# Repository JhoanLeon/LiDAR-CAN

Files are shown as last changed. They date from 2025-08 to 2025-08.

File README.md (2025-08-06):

# LiDAR-CAN BRDIGE MODULE - CASE STUDY Robot.com

This project was developed for a Robot.com case study. The entire project was developed using Git/GitHub version control so you can view all commits and incremental progress throughout the project's execution.

The requested deliverables for this case study are located in the OUTPUT folder.

For any questions, suggestions, or recommendations, please contact me by email: je.leon.e@outlook.com

Note: This project is available as a public GitHub repository at the following link: https://github.com/JhoanLeon/LiDAR-CAN

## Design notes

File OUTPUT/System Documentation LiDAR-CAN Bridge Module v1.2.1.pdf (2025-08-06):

## System Documentation

## LiDAR-CAN Bridge Module v1.2.1

### General Description:

The system will handle data flow from MID-360 LiDAR sensor Ethernet interface to CAN-FD bus by using the STM32F401RBT6 MCU as the central processor and data bridge. This MCU will manage the communication between the W5500 Ethernet controller and the TCAN4550RGY CAN-FD controller through independent high-speed SPI buses. Data from the LiDAR will be received via Ethernet, processed by the MCU, and then re-packaged and transmitted onto the CAN-FD bus. Additionally, the board have internal power management circuits to regulate input power to suitable +12VDC and +3.3VDC levels to use in the system components.

### 1. Data Flow Description:

The data flow in the board can be described in four main stages:

1.1. Ethernet Data Reception (LiDAR to W5500):
The Livox MID-360 LiDAR sends point cloud and other data over the Ethernet connection. This data, which is typically encapsulated in UDP packets, is received by the W5500 Ethernet Controller. The W5500's primary role is to handle the low-level physical and data link layers of the Ethernet protocol. It’s hardwired TCP/IP stack automatically manages the network protocol headers and places the payload data into its internal TX/RX buffers.
1.2. Data Transfer (W5500 to STM32F401):
The W5500 notifies the STM32F401RBT6 MCU that new data has arrived in its RX buffer by asserting the interrupt line. The MCU then uses the high-speed SPI bus to read the data from the W5500's buffers. The STM32's firmware is responsible for a few key tasks here:
- Reading the UDP payload from the W5500's buffers.
- Parsing the received data to extract relevant information, such as the point cloud data, time stamps, or status messages.
- Implementing any protocol translation or data filtering logic.
1.3. Data Processing and Translation (STM32F401 MCU):
The STM32F401 MCU will process the raw data from the LiDAR and re-format it into CAN-FD frames. This involves:
- Packet Parsing: Extracting specific data fields from the Ethernet packets. The raw LiDAR point cloud data is often too large to fit into a single CAN-FD frame.
- Data Aggregation or Fragmentation: Depending on the data being sent, the MCU may need to aggregate smaller data points into a single CAN-FD frame or, more likely, fragment larger data sets across multiple CAN-FD frames.
- Frame Construction: Building the CAN-FD frames with the appropriate identifier, payload, and control bits as required by the CAN-FD network protocol.
1.4. CAN-FD Data Transmission (STM32F401 to TCAN4550RGY):
Once a CAN-FD frame is constructed in the MCU's memory, the STM32F401 uses its second high-speed SPI bus to write the frame data and control commands to the TCAN4550RGY CAN-FD Controller. The TCAN4550's internal CAN-FD controller takes over from there, managing the CAN-FD protocol, arbitration, and transmission. It then uses its integrated CAN-FD transceiver to convert the digital signals into the analog differential signals required for the physical CAN-FD bus.

### 2. Proposed Test Strategy:

This board was designed with different features to facilitate testing in PCBA prototypes. General DFM and DFT guidelines were used to ensure that the final system can be actually manufactured, assembled, and tested.

2.1. Hardware Validation:
This phase ensures that the board's power delivery and physical connections are correct before introducing any firmware.
- Visual Inspection: Physically inspect the board for any solder bridges, misaligned components, or missing parts.
- Continuity Check: Use a multimeter in continuity mode to check for unintended shorts, especially between power and ground pins on each IC.
- Voltage Measurement: Apply input power and use a multimeter to measure the output voltage at each regulator's output. Verify the readings match the expected values (3.3V and 12V). Use the on-board test points to measure voltages with higher precision and less risk of shorting.
- LED Indicators: Confirm that the power rail LEDs illuminate correctly (D2=12V OK, D4=3.3V OK).
- Board bring-up: Place the R1 and R2 jumpers to power a single voltage rail at a time and confirm their voltage levels on the complete PDN (Power Delivery Network).
2.2. MCU Bring-Up and Basic Firmware Test:
- MCU Power: Ensure the MCU's power rail is stable and correctly supplied.
- Debugger Connection: Connect the SWD programmer/debugger to the board's SWD interface (J5).
- Basic Firmware: Write a simple "blink" firmware that toggles the USER LED pin (PA2) of the MCU.
- Programming and Test: Program the MCU with this firmware. A successful upload and the blinking USER LED confirm the MCU is powered, clocked, and programmable. This validates the SWD interface and the fundamental MCU operation.
2.3. Peripheral Validation (Modular Approach):
This phase uses basic firmware to test each peripheral independently. Start with one, then add the next.
2.3.1. W5500 Ethernet Controller Test:
- SPI Communication: Write firmware to initialize the W5500 via its dedicated SPI bus. Send simple commands and read back a known register value (e.g., the VERSIONR register) to confirm the SPI communication is working. Use a logic analyzer or oscilloscope on the SPI test points to debug any issues.
- Link Status: Connect an Ethernet cable from the W5500 to a PC or switch. Write firmware to read the link status register on the W5500. The W5500's own status LEDs should also indicate a successful link.
- Echo Server Test: Implement a simple UDP or TCP echo server in the firmware using the W5500's hardwired stack. Send a packet from a PC to the board and verify that the board echoes the packet back. This confirms the entire Ethernet data path is functional.
2.3.2. TCAN4550RGY CAN-FD Controller Test:
- SPI Communication: Write firmware to initialize the TCAN4550 via its dedicated SPI bus. Read and write to registers to confirm the SPI communication is stable. Again, use a logic analyzer on the SPI test points if needed.
- CAN Loopback Test: The TCAN4550 can be put into a loopback mode where it transmits a message and immediately receives it back internally. Write firmware to configure this mode, send a CAN-FD frame, and check for the received frame in the RX buffer. This verifies the controller's functionality without a physical bus connection.
- Physical Bus Test: Connect the board to a known good CAN-FD node (e.g., a PC with a CAN interface). Write firmware to transmit a simple CAN-FD message. Use a CAN bus analyzer to confirm the message is correctly transmitted and received by the other node. This validates the TCAN4550's transceiver and the physical bus wiring.
2.4. Full System Integration and Data Flow:
Once all subsystems are validated individually, proceed with the final functional test developing a complete firmware for the bridge. This firmware should:
- Initialize both the W5500 and TCAN4550.
- Wait for a command or data packet from the Livox MID-360 over Ethernet.
- Once received, read the data from the W5500 via the MCU SPI 2 Bus.
- Process the data and construct a CAN-FD frame.
- Send the CAN-FD frame to the TCAN4550 via the MCU SPI 1 Bus for transmission on the physical CAN-FD bus.

Finally connect the Livox MID-360, Bridge module, and a CAN bus analyzer to run the complete code and monitor the CAN bus analyzer to confirm that the corresponding CAN-FD frames are correctly received.

Note: The user LED can be used as a status indicator at each stage of this process (e.g., blinking slowly for Ethernet link up, blinking fast for a CAN message transmitted).

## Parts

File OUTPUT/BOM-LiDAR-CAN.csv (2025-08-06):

# | Reference | Qty | Value | Description | Manufacturer | MPN | DNP
1 | C2 | 1 | 1nF | CAP CER 1808 1NF 2000V X7R 20% | KEMET | C1808C102MGRACAUTO
2 | C33 | 1 | 330nF | CAP CER 0.33UF 50V X7R 0603 | KYOCERA AVX | KGM15BR71H334KT
3 | C1,C5 | 2 | 4.7nF | CAP CER 4700PF 50V X7R 0603 | YAGEO | CC0603KRX7R9BB472
4 | C14,C17,C26,C28,C30,C34 | 6 | 10uF | CAP CER 10UF 25V X5R 0603 | KYOCERA AVX | KGM15CR51E106KT
5 | C20,C21,C24,C42 | 4 | 10nF | CAP CER 10000PF 50V X7R 0603 | YAGEO | CC0603KRX7R9BB103
6 | C22,C23,C31,C32,C39,C40 | 6 | 8pF | CAP CER 8PF 50V C0G/NPO 0603 | YAGEO | CC0603DRNPO9BN8R0
7 | C25,C41 | 2 | 4.7uF | CAP CER 4.7UF 16V X5R 0603 | YAGEO | CC0603KRX5R7BB475
8 | C3,C4 | 2 | 100pF | CAP CER 100PF 50V C0G/NPO 0603 | YAGEO | CC0603JRNPO9BN101
9 | C6,C10,C15,C16,C18,C19,C27,C29,C35,C36,C37,C38,C43 | 13 | 100nF | CAP CER 0.1UF 50V X7R 0603 | KYOCERA AVX | KGM15BR71H104KM
10 | C7,C11 | 2 | 2.2uF | CAP CER 2.2UF 50V X7R 0805 | YAGEO | CC0805KKX7R9BB225
11 | C8,C9,C12,C13 | 4 | 22uF | CAP CER 22UF 25V X5R 0805 | Samsung Electro-Mechanics | CL21A226MAYNNNE
12 | D1 | 1 | NUP2105L | TVS DIODE 24VWM 44VC SOT233 | onsemi | SZNUP2105LT1G
13 | D3 | 1 | 5.1V | DIODE ZENER 5.1V 1W SMA | Diodes Incorporated | SMAZ5V1-13-F
14 | D6 | 1 | 12V | DIODE ZENER 12V 1.5W SMA | onsemi | 1SMA5927BT3G
15 | D2,D4,D5 | 3 | GREEN | LED GREEN CLEAR CHIP SMD 0603 | Lite-On Inc. | LTST-C190GKT
16 | FB1 | 1 | MH1608-800Y | FERRITE BEAD 80 OHM 0603 1LN | Bourns Inc. | MH1608-800Y
17 | J3 | 1 | G7LX-A88S7-BP-G/Y | 1 Port RJ45 Through Hole 10/100 Base-T | Kycon, Inc. | G7LX-A88S7-BP-G/Y
18 | J5 | 1 | 61300511121 | CONN HEADER VERT 5POS 2.54MM | Wurth Elektronik | 61300511121
19 | J1,J2,J4 | 3 | XT30(2+2) | Power connector XT30 PCB RA | Changzhou Amass Elec | XT30PW(2+2)-M.G.B
20 | L1 | 1 | 12uH | FIXED IND 12UH 2.2A 58 MOHM SMD | Abracon LLC | ASPI-6045S-120M-T
21 | L2 | 1 | 5.6uH | IND,3X3X1.3MM,5.6UH20%,1.8A,SHD | Bourns Inc. | SRN3015C-5R6M
22 | R13 | 1 | 5.23k | RES 5.23K OHM 1% 1/10W 0603 | YAGEO | RC0603FR-075K23L
23 | R16 | 1 | 22.1k | RES 22.1K OHM 1% 1/10W 0603 | YAGEO | RC0603FR-0722K1L
24 | R26 | 1 | 12.4k | RES 12.4K OHM 1% 1/10W 0603 | YAGEO | RC0603FR-0712K4L
25 | R34 | 1 | 22R | RES 22 OHM 5% 1/8W 0805 | YAGEO | RC0805JR-0722RL
26 | R1,R2 | 2 | 0R | RES 0 OHM JUMPER 0805 | YAGEO | 13-AC0805JR-130RLCT-ND
27 | R11,R14 | 2 | 100k | RES 100K OHM 1% 1/10W 0603 | YAGEO | RT0603FRE13100KL
28 | R17,R18,R19,R20 | 4 | 49.9R | RES 49.9 OHM 1% 1/10W 0603 | YAGEO | RC0603FR-0749R9L
29 | R21,R22 | 2 | 10R | RES SMD 10 OHM 5% 1/10W 0603 | YAGEO | AC0603JR-0710RL
30 | R23,R24,R25,R27,R28,R31,R33 | 7 | 10k | RES 10K OHM 5% 1/10W 0603 | YAGEO | RC0603JR-0710KL
31 | R29,R30 | 2 | 0R | RES 0 OHM JUMPER 1/10W 0603 | YAGEO | RC0603JR-070RL
32 | R3,R4,R12,R15,R32 | 5 | 300R | RES 300 OHM 5% 1/10W 0603 | YAGEO | RC0603JR-07300RL
33 | R5,R6,R7,R8 | 4 | 75R | RES SMD 75 OHM 5% 1/10W 0603 | YAGEO | AC0603JR-0775RL
34 | R9,R10 | 2 | 59R | RES 59 OHM 1% 1/10W 0603 | YAGEO | RC0603FR-0759RL
35 | SW1 | 1 | RST | SWITCH TACTILE SPST-NO 0.05A 12V | C&K | RS-282G05A3-SM RT
36 | U3 | 1 | W5500 | IC CTLR 3-1 ETH TCP/IP 48LQFP | WIZnet | W5500
37 | U4 | 1 | TCAN4550RGY | IC CAN FD CONTROLLER 20-VQFN | Texas Instruments | TCAN4550RGYRQ1
38 | U5 | 1 | STM32F401RBT6 | IC MCU 32BIT 128KB FLASH 64LQFP | STMicroelectronics | STM32F401RBT6
39 | U1,U2 | 2 | LMR51430 | IC REG BUCK ADJ 3A SOT23 | Texas Instruments | LMR51430XDDCR
40 | Y2 | 1 | 40MHz | CRYSTAL 40.000 MHZ 6PF SMD | ECS Inc. | ECS-400-6-37Q-RES-TR
41 | Y1,Y3 | 2 | 25MHz | CRYSTAL 25 MHZ 6PF SMD | ECS Inc. | ECS-250-6-37B2-AGY-TR

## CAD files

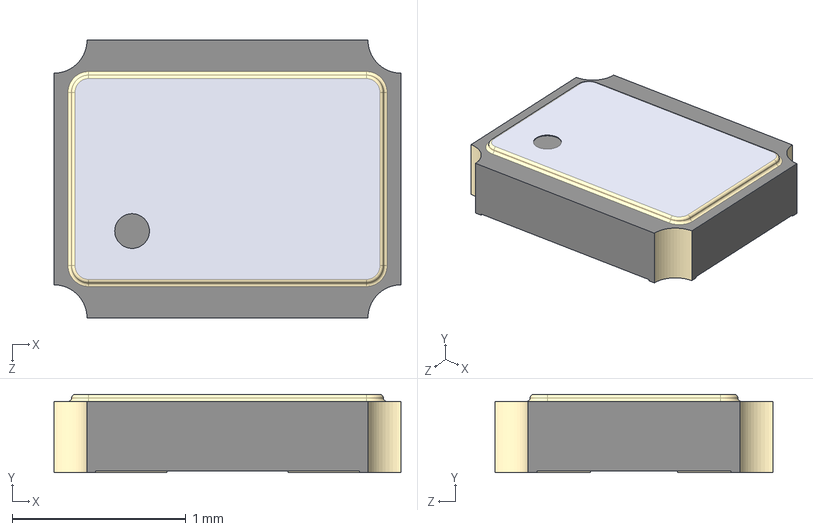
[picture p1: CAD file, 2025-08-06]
LiDAR-CAN/LOCAL_LIBRARY/ECS-250-6-37B2-AGY-TR.stp
2.00 x 0.45 x 1.60 mm

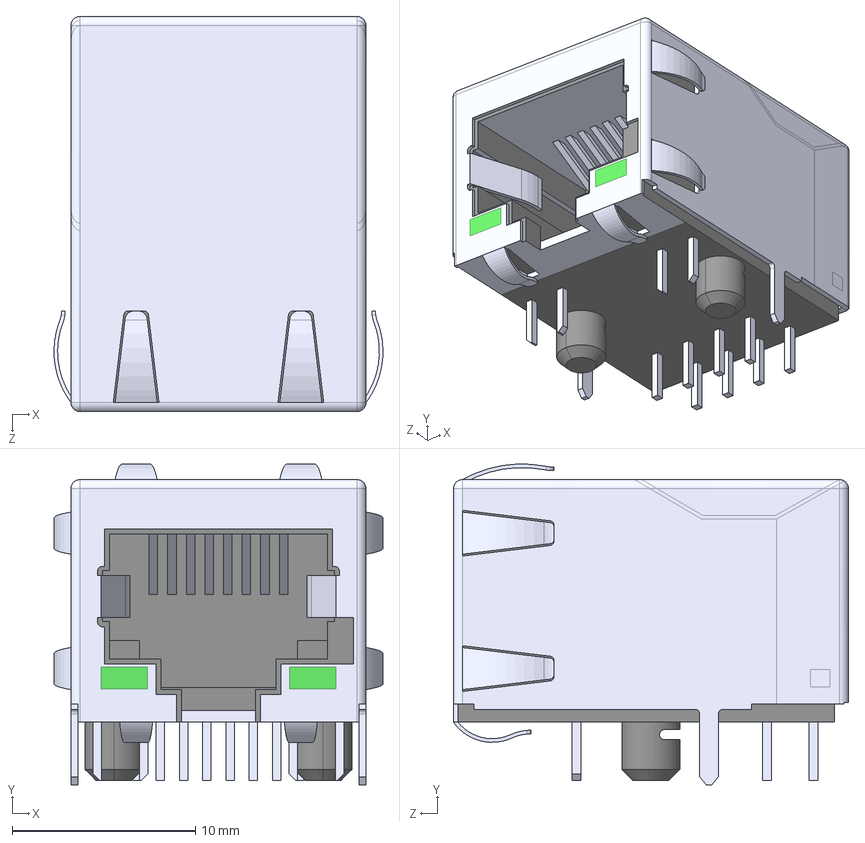
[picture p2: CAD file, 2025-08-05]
LiDAR-CAN/LOCAL_LIBRARY/SI-60062-F.stp
18.0 x 17.5 x 21.6 mm

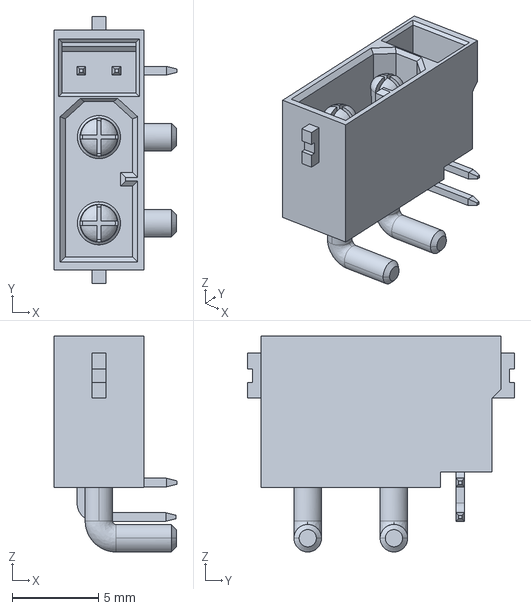
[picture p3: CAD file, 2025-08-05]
LiDAR-CAN/LOCAL_LIBRARY/XT30(2+2)PW-M.STEP
7.12 x 15.5 x 12.5 mm

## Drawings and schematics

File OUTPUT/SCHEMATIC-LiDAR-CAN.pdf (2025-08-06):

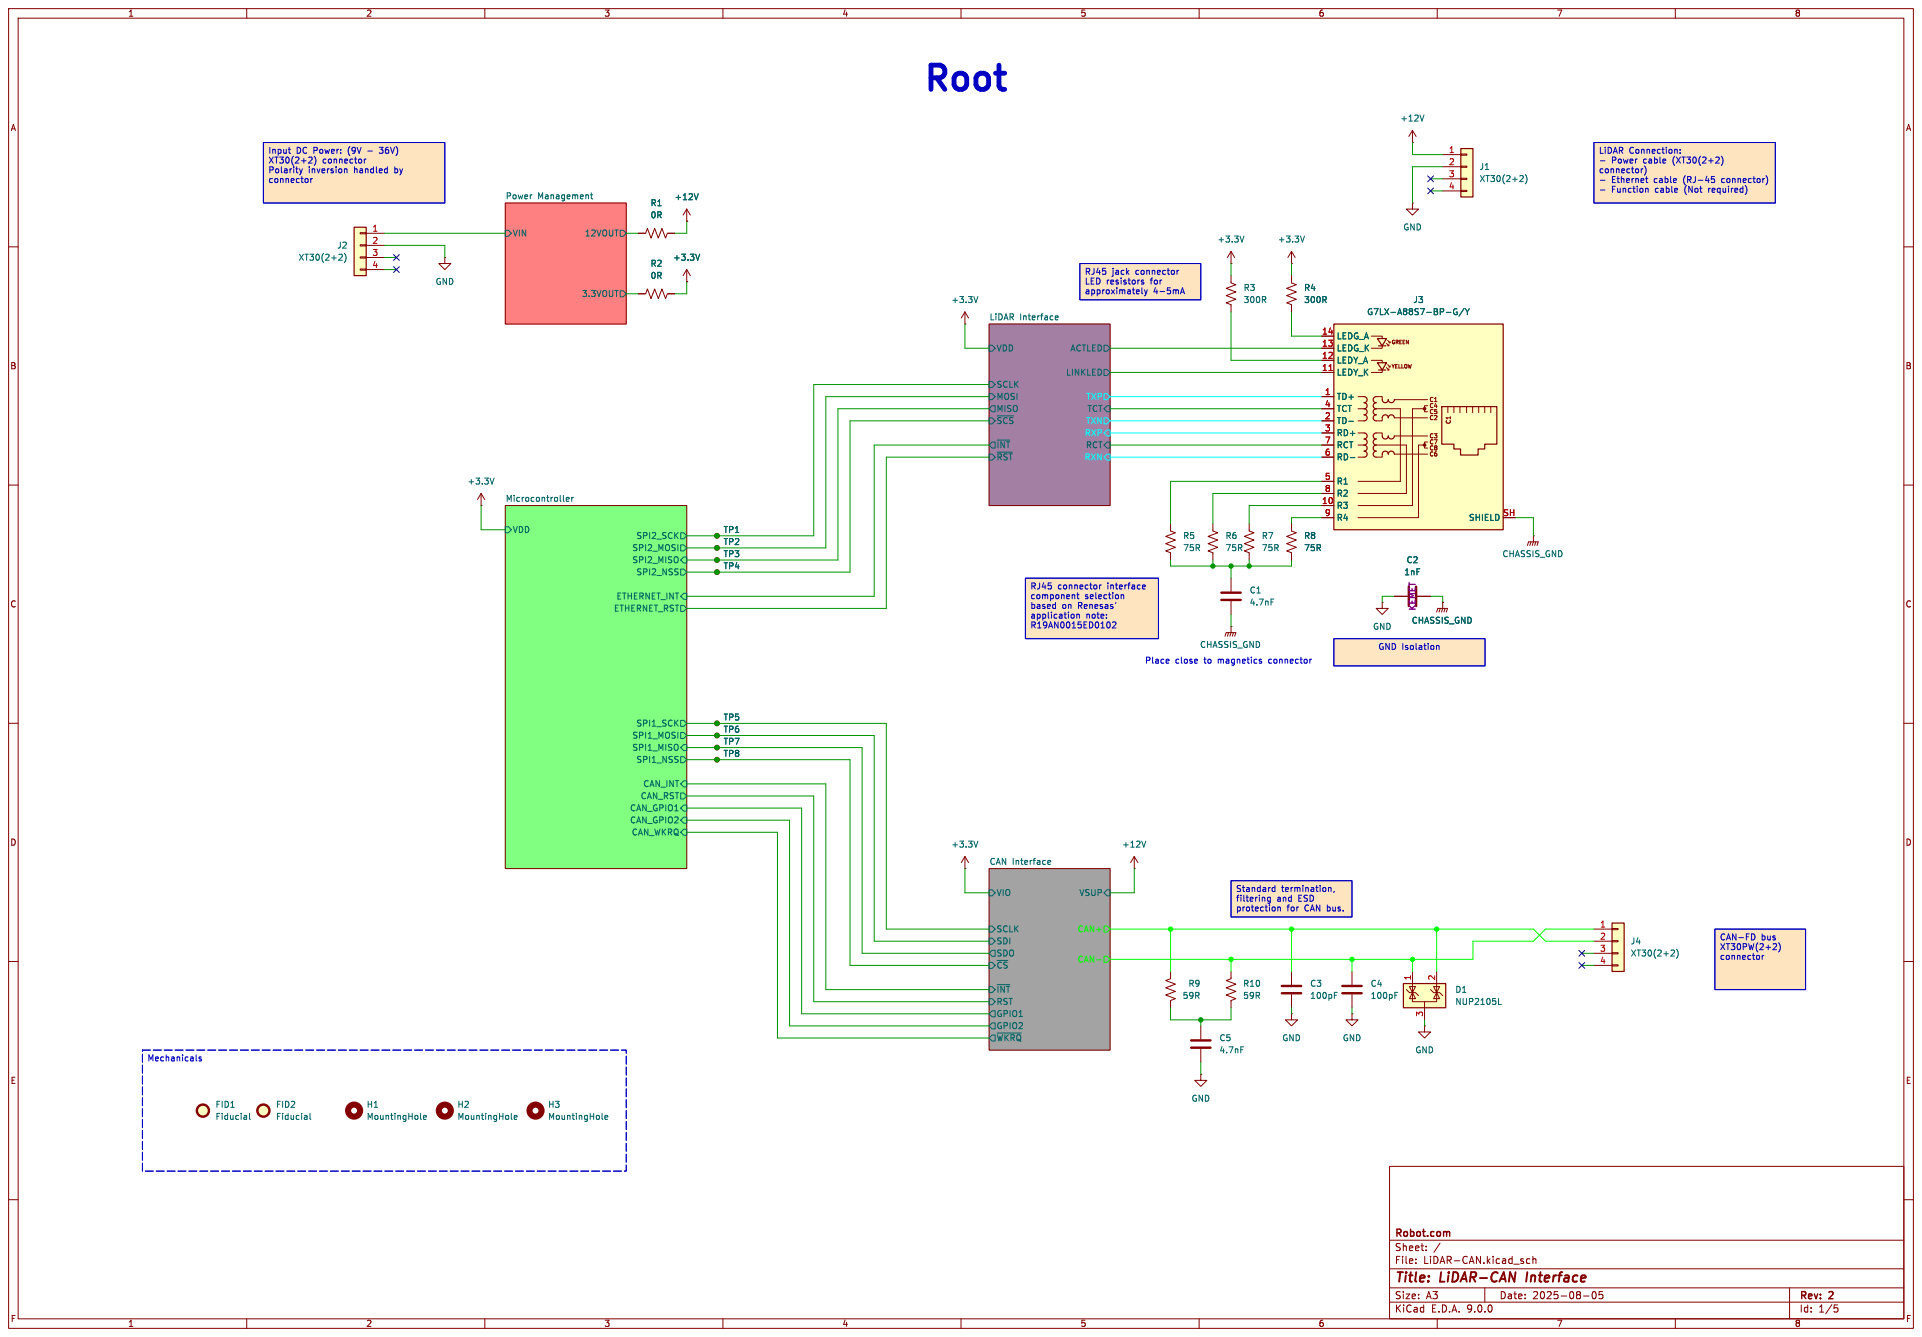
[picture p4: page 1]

LiDAR Connection: - Power cable (XT30(2+2)

Id: 1/5 Title: LiDAR-CAN Interface

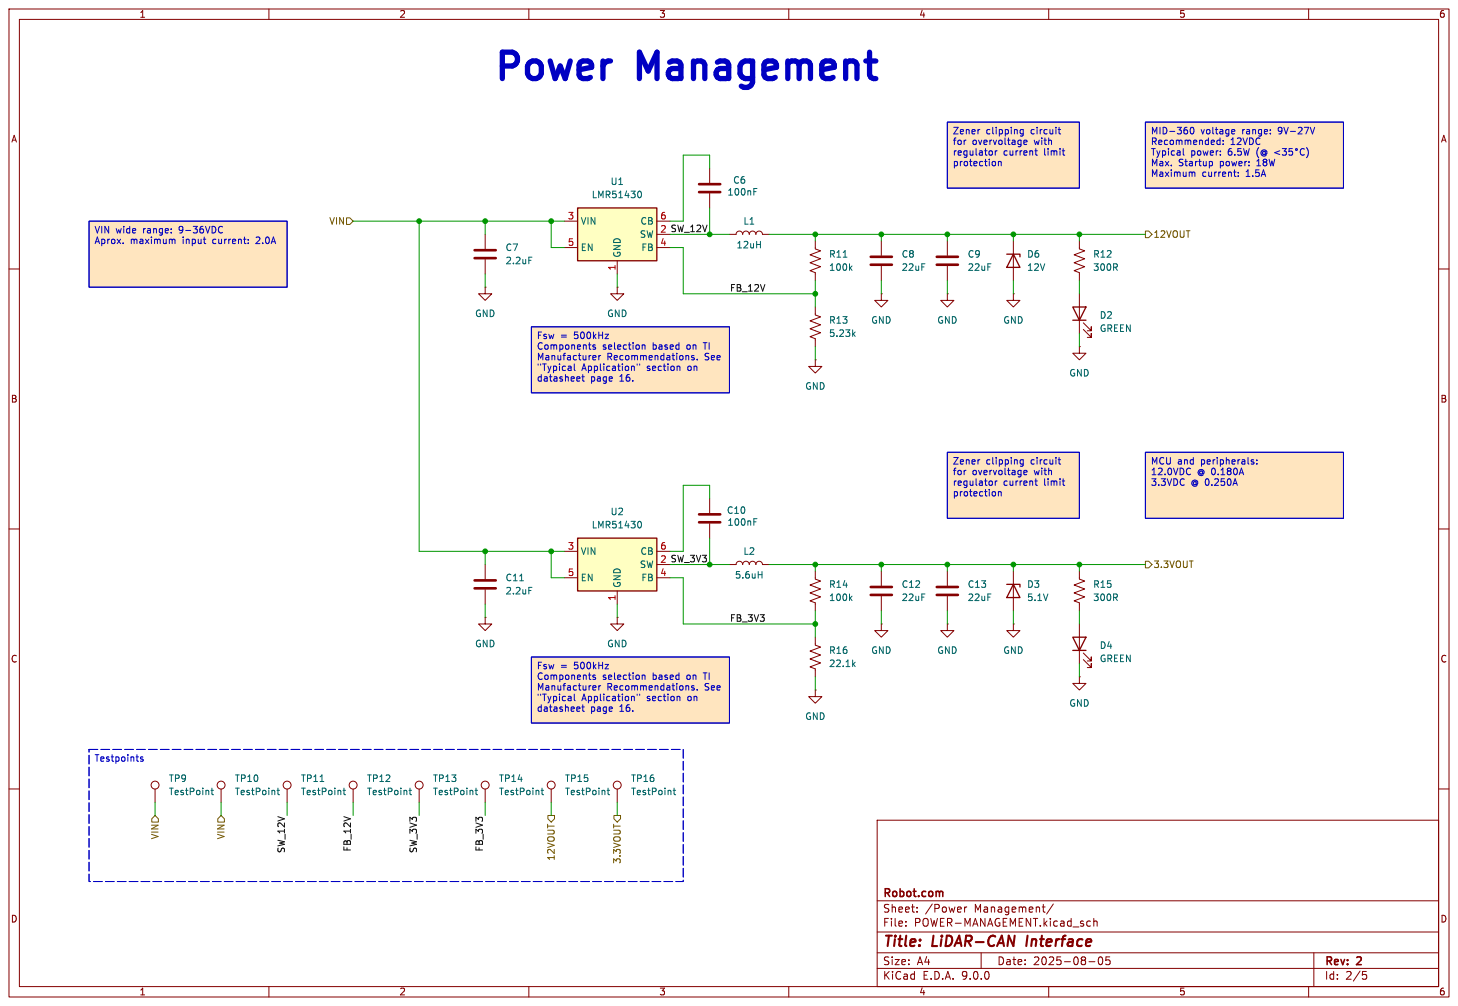
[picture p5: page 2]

Typical power: 6.5W (@ þÿ<35°C) Max. Startup power: 18W

Id: 2/5 Title: LiDAR-CAN Interface

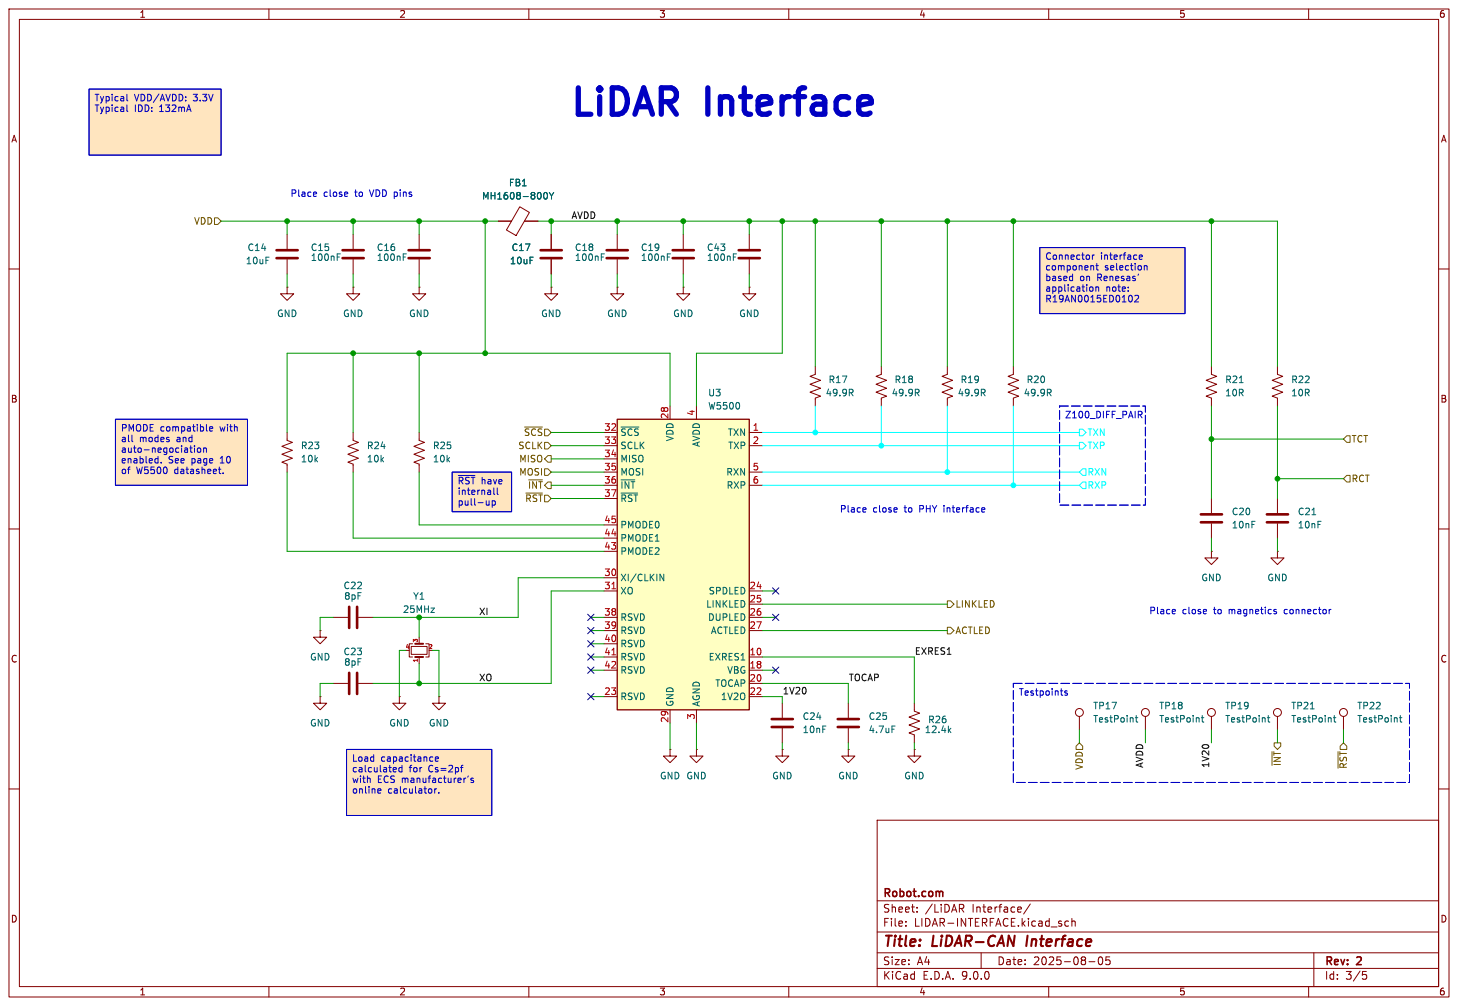
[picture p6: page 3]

of W5500 datasheet. Typical VDD/AVDD: 3.3V
Typical IDD: 132mA

3 TXN 1 TXP 2 RXN 5 RXP 6 SPDLED 24

Id: 3/5 Title: LiDAR-CAN Interface

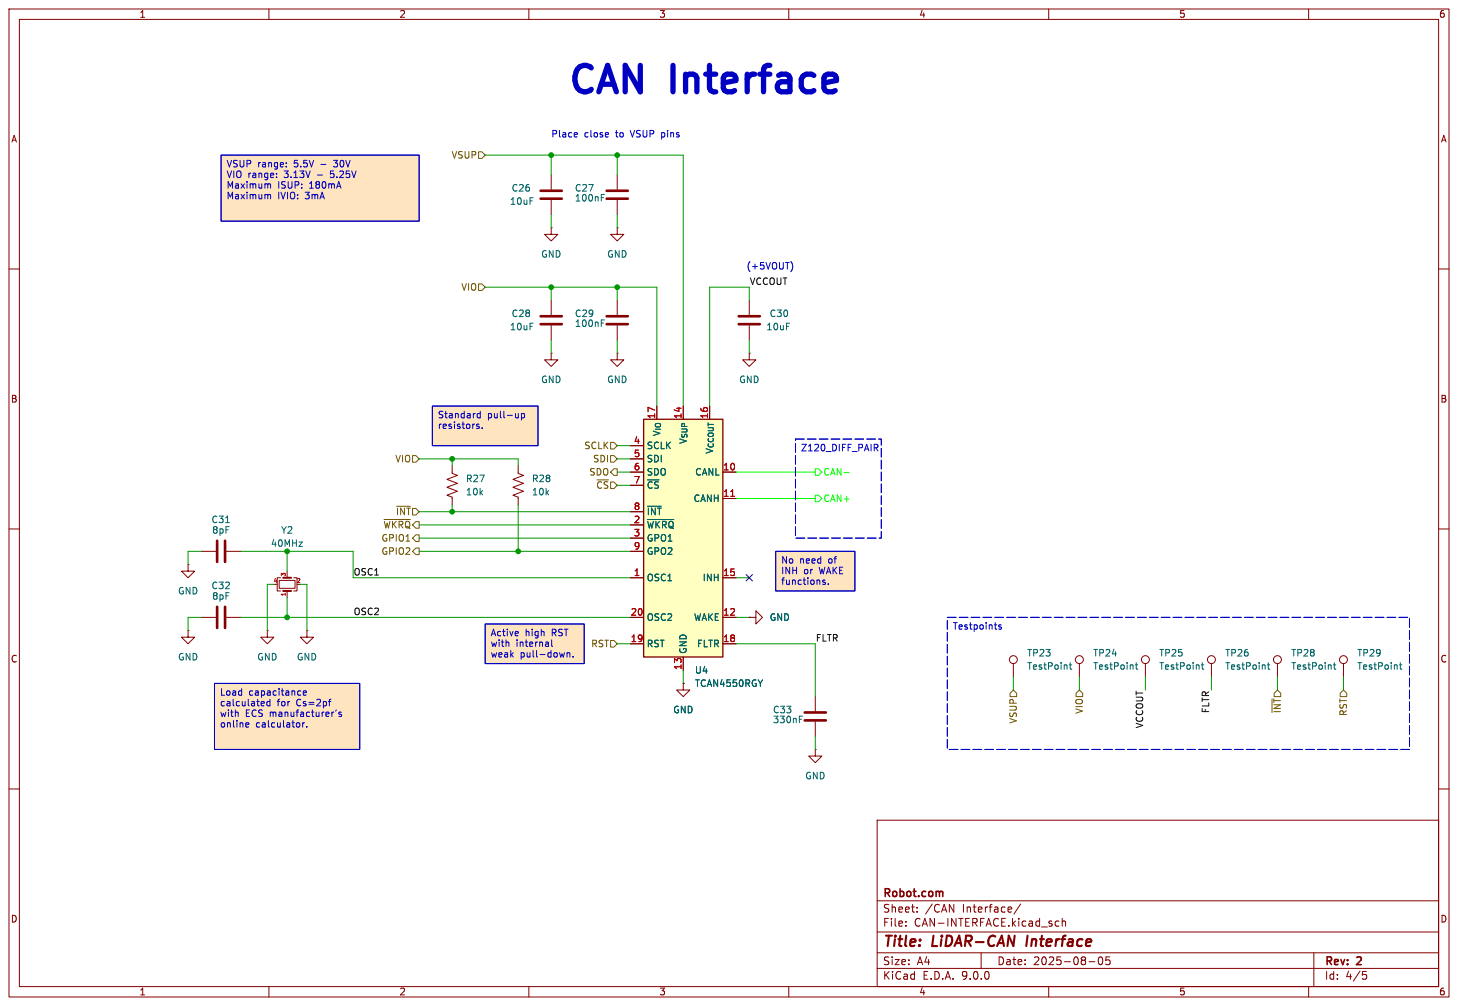
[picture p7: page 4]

VSUP range: 5.5V - 30V
VIO range: 3.13V - 5.25V Maximum ISUP: 180mA Maximum IVIO: 3mA

Active high RST with internal weak pull-down. Standard pull-up

Id: 4/5 Title: LiDAR-CAN Interface

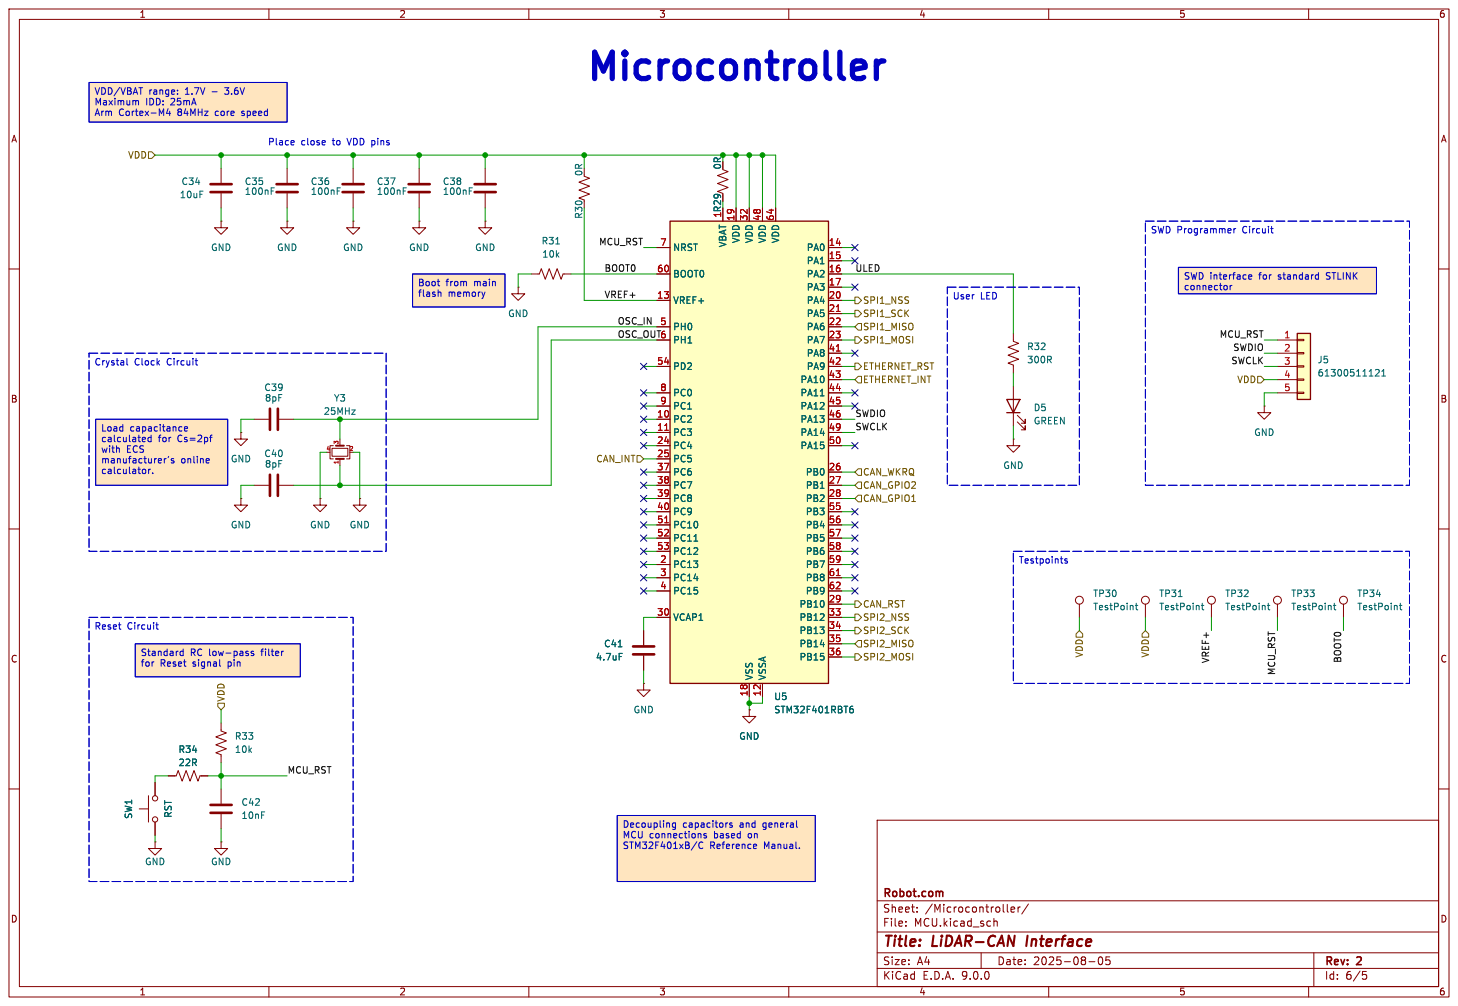
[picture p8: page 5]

VDD/VBAT range: 1.7V - 3.6V Maximum IDD: 25mA

connector Place close to VDD pins

1 VDD 19 VDD 32 VSS 18 VDD 48 VSSA 12 VDD 64 PA0 14 PA1 15 PA2 16 PA3 17 PA4 20 PA5 21 PA6 22 PA7 23 PA8 41 PA9 42 PA10 43 PA11 44 PA12 45 PA13 46 PA14 49 PA15 50 PB0 26 PB1 27 PB2 28 PB3 55 PB4 56 PB5 57 PB6 58 PB7 59 PB8 61 PB9 62 PB10 29 PB12 33 PB13 34 PB14 35 PB15 36 R29 0R

1 VDD 19 VDD 32 VSS 18 VDD 48 VSSA 12 VDD 64 PA0 14 PA1 15 PA2 16 PA3 17 PA4 20 PA5 21 PA6 22 PA7 23 PA8 41 PA9 42 PA10 43 PA11 44 PA12 45 PA13 46 PA14 49 PA15 50 PB0 26 PB1 27 PB2 28 PB3 55 PB4 56 PB5 57 PB6 58 PB7 59 PB8 61 PB9 62 PB10 29 PB12 33 PB13 34 PB14 35 PB15 36 U5STM32F401RBT6

Crystal Clock Circuit Load capacitance

File: MCU.kicad_sch Sheet: /Microcontroller/ Robot.com

Id: 6/5 Title: LiDAR-CAN Interface

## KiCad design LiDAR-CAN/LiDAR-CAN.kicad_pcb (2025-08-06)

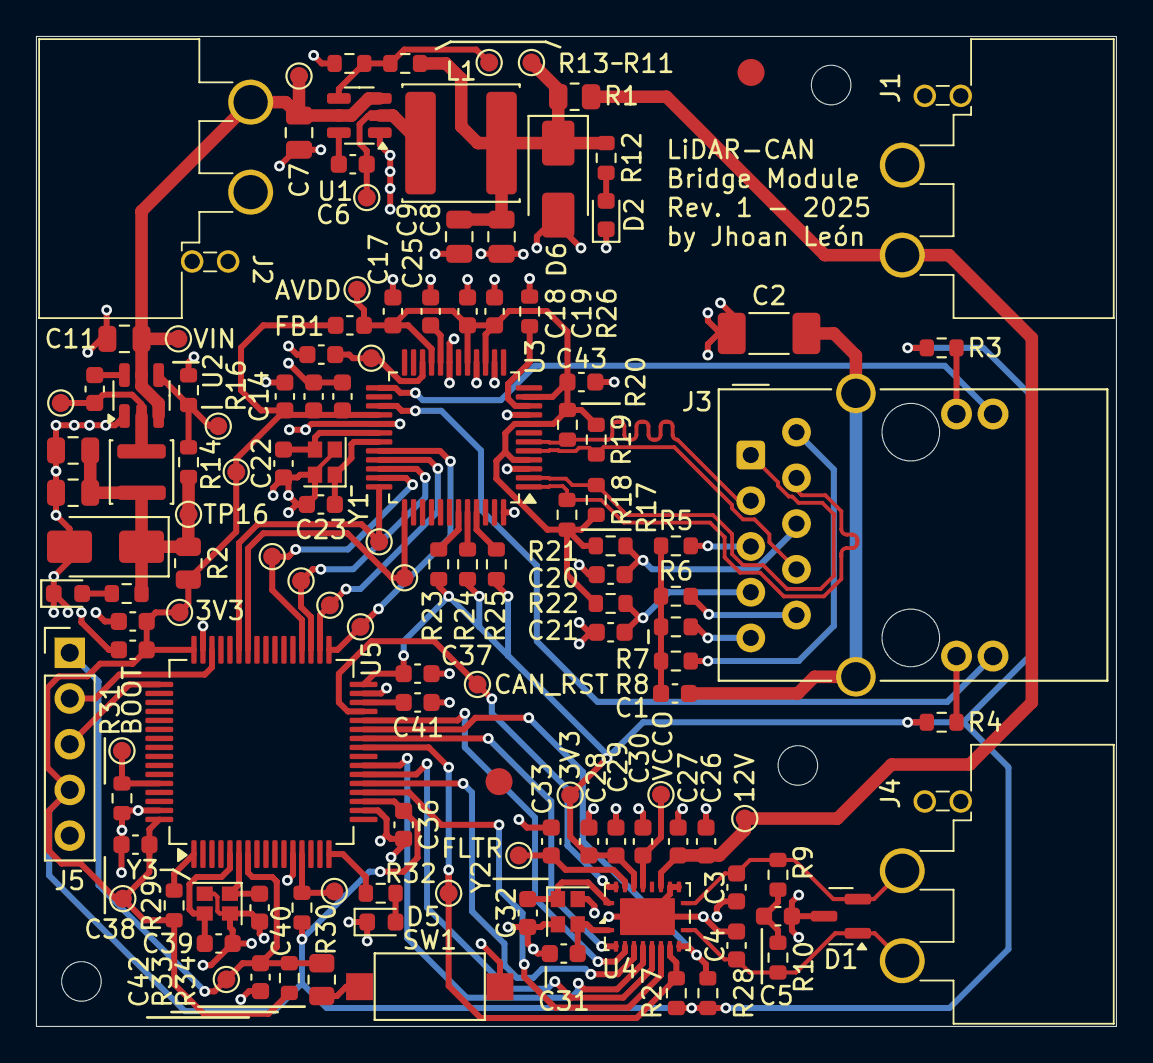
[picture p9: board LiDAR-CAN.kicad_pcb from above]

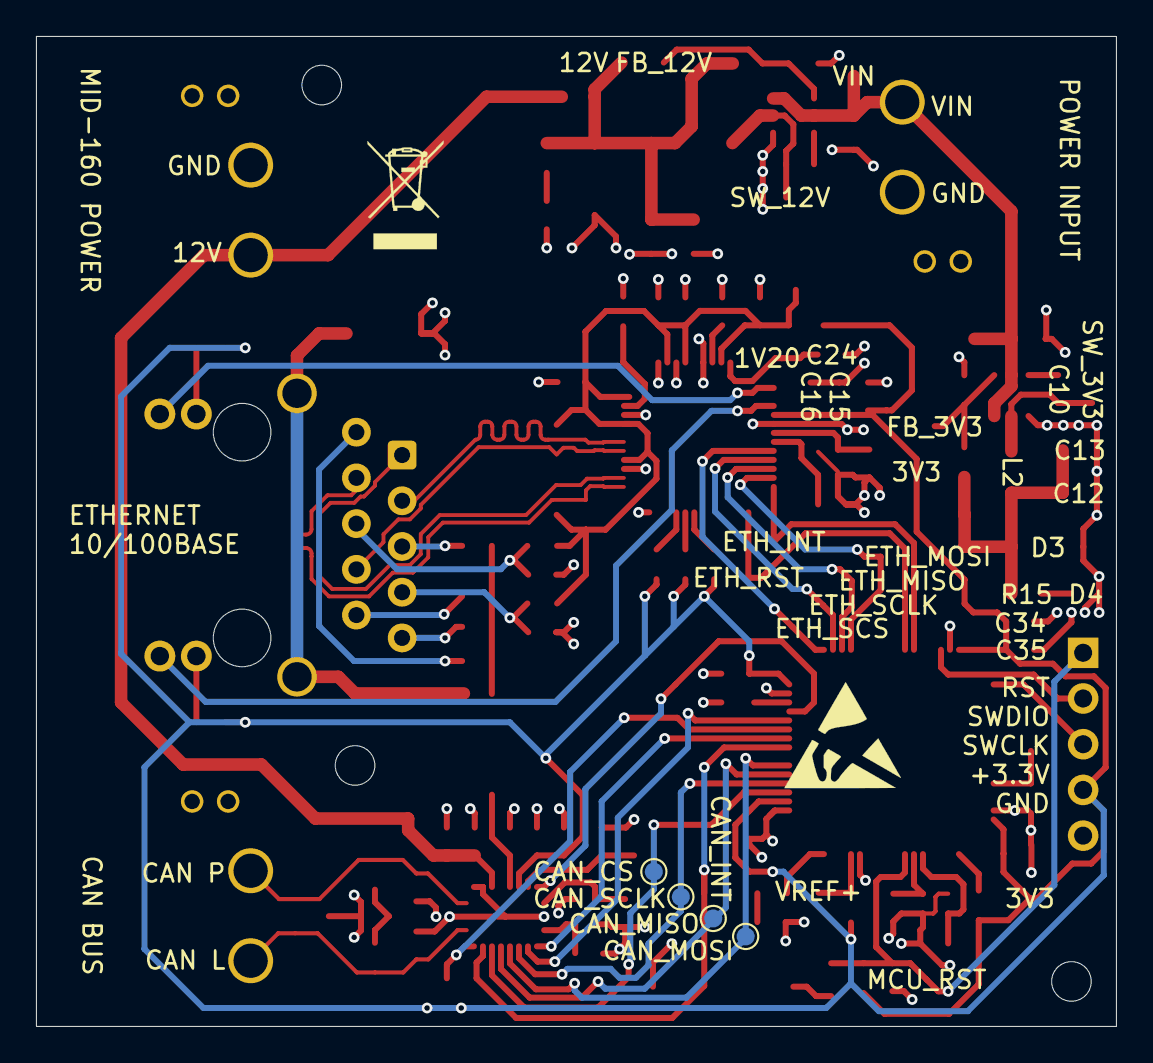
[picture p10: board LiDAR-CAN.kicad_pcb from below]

Board: 4 copper layers, 60.0 x 55.0 mm, 137 parts (4 on the bottom side), 73 nets.

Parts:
1V20, 3V3, 3V3#2, 3V3#3, 3V3#4, 12V, 12V#2: TestPoint; TestPoint_Pad_D1.0mm
AVDD: TestPoint; TestPoint_Pad_D1.0mm
BOOT: TestPoint; TestPoint_Pad_D1.0mm
C1, C5: 4.7nF; C_0603_1608Metric
C2: 1nF; C_1808_4520Metric
C3, C4: 100pF; C_0603_1608Metric
C6, C10, C15, C16, C18, C19, C27, C29, C35, C36, C37, C38, C43: 100nF; C_0603_1608Metric
C7, C11: 2.2uF; C_0805_2012Metric
C8, C9, C12, C13: 22uF; C_0805_2012Metric
C14, C17, C26, C28, C30, C34: 10uF; C_0603_1608Metric
C20, C21, C24, C42: 10nF; C_0603_1608Metric
C22, C23, C31, C32, C39, C40: 8pF; C_0603_1608Metric
C25, C41: 4.7uF; C_0603_1608Metric
C33: 330nF; C_0603_1608Metric
CAN_CS: TestPoint_Small; TestPoint_Pad_D1.0mm
CAN_INT: TestPoint; TestPoint_Pad_D1.0mm
CAN_MISO: TestPoint_Small; TestPoint_Pad_D1.0mm
CAN_MOSI: TestPoint_Small; TestPoint_Pad_D1.0mm
CAN_RST: TestPoint; TestPoint_Pad_D1.0mm
CAN_SCLK: TestPoint_Small; TestPoint_Pad_D1.0mm
D1: NUP2105L; SOT-23
D2, D4, D5: GREEN; LED_0603_1608Metric
D3: 5.1V; D_SMA
D6: 12V; D_SMA
ETH_INT: TestPoint; TestPoint_Pad_D1.0mm
ETH_MISO: TestPoint_Small; TestPoint_Pad_D1.0mm
ETH_MOSI: TestPoint_Small; TestPoint_Pad_D1.0mm
ETH_RST: TestPoint; TestPoint_Pad_D1.0mm
ETH_SCLK: TestPoint_Small; TestPoint_Pad_D1.0mm
ETH_SCS: TestPoint_Small; TestPoint_Pad_D1.0mm
FB1: MH1608-800Y; L_0603_1608Metric
FB_3V3, FB_12V: TestPoint; TestPoint_Pad_D1.0mm
FID1, FID2: Fiducial; Fiducial_1.5mm_Mask3mm
FLTR: TestPoint; TestPoint_Pad_D1.0mm
H1, H2, H3: MountingHole; MountingHole_2.2mm_M2
J1, J2, J4: XT30(2+2); XT30PW(2+2)-M.G.B
J3: G7LX-A88S7-BP-G/Y; RJ45_Kycon_G7LX-A88S7-BP-xx_Horizontal
J5: 61300511121; PinHeader_1x05_P2.54mm_Vertical
L1: 12uH; L_APV_ANR6020
L2: 5.6uH; L_APV_ANR3015
MCU_RST: TestPoint; TestPoint_Pad_D1.0mm
R1, R2: 0R; R_0805_2012Metric
R3, R4, R12, R15, R32: 300R; R_0603_1608Metric
R5, R6, R7, R8: 75R; R_0603_1608Metric
R9, R10: 59R; R_0603_1608Metric
R11, R14: 100k; R_0603_1608Metric
R13: 5.23k; R_0603_1608Metric
R16: 22.1k; R_0603_1608Metric
R17, R18, R19, R20: 49.9R; R_0603_1608Metric
R21, R22: 10R; R_0603_1608Metric
R23, R24, R25, R27, R28, R31, R33: 10k; R_0603_1608Metric
R26: 12.4k; R_0603_1608Metric
R29, R30: 0R; R_0603_1608Metric
R34: 22Ω; R_0805_2012Metric
SW1: RST; SW_SPST_CK_RS282G05A3
SW_3V3, SW_12V: TestPoint; TestPoint_Pad_D1.0mm
TP16: TestPoint; TestPoint_Pad_D1.0mm
U1, U2: LMR51430; SOT-23-6
U3: W5500; LQFP-48_7x7mm_P0.5mm
U4: TCAN4550RGY; Texas_RGY_R-PVQFN-N20_EP2.05x3.05mm
U5: STM32F401RBT6; LQFP-64_10x10mm_P0.5mm
VCCO: TestPoint; TestPoint_Pad_D1.0mm
VIN: TestPoint; TestPoint_Pad_D1.0mm
VIN#2: TestPoint; TestPoint_Pad_D1.0mm
VREF+: TestPoint; TestPoint_Pad_D1.0mm
Y1, Y3: 25MHz; Crystal_SMD_2016-4Pin_2.0x1.6mm
Y2: 40MHz; Crystal_SMD_2016-4Pin_2.0x1.6mm

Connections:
+3.3V: 3V3.1, 3V3#2.1, 3V3#3.1, 3V3#4.1, C14.1, C15.2, C16.2, C28.1, C29.2, C34.1, C35.2, C36.2, C37.2, C38.2, FB1.1, J5.4, R2.2, R3.1, R4.1, R23.1, R24.1, R25.1, R27.1, R28.1, R29.2, R30.2, R33.1, U3.28 (VDD), U4.17 (V_{IO}), U5.19 (VDD), U5.32 (VDD), U5.48 (VDD), U5.64 (VDD)
+12V: 12V.1, C26.1, C27.2, J1.1, R1.2, U4.14 (V_{SUP})
/CAN Interface/CAN+: C3.1, D1.2 (K), J4.2, R9.2, U4.11 (CANH)
/CAN Interface/CAN-: C4.1, D1.1 (K), J4.1, R10.2, U4.10 (CANL)
/CAN Interface/FLTR: C33.2, FLTR.1, U4.18 (FLTR)
/CAN Interface/GPIO1: U4.3 (GPO1), U5.28 (PB2)
/CAN Interface/GPIO2: R28.2, U4.9 (GPO2), U5.27 (PB1)
/CAN Interface/OSC1: C31.2, U4.1 (OSC1), Y2.3
/CAN Interface/OSC2: C32.2, U4.20 (OSC2), Y2.1
/CAN Interface/RST: CAN_RST.1, U4.19 (RST), U5.29 (PB10)
/CAN Interface/SCLK: CAN_SCLK.1, U4.4 (SCLK), U5.21 (PA5)
/CAN Interface/SDI: CAN_MOSI.1, U4.5 (SDI), U5.23 (PA7)
/CAN Interface/SDO: CAN_MISO.1, U4.6 (SDO), U5.22 (PA6)
/CAN Interface/VCCOUT: C30.1, U4.16 (V_{CCOUT}), VCCO.1
/CAN Interface/~CS: CAN_CS.1, U4.7 (~CS), U5.20 (PA4)
/CAN Interface/~INT: CAN_INT.1, R27.2, U4.8 (~INT), U5.25 (PC5)
/CAN Interface/~WKRQ: U4.2 (~WKRQ), U5.26 (PB0)
/LiDAR Interface/1V20: 1V20.1, C24.1, U3.22 (1V2O)
/LiDAR Interface/ACTLED: J3.13 (LEDG_K), U3.27 (ACTLED)
/LiDAR Interface/AVDD: AVDD.1, C17.1, C18.2, C19.2, C43.2, FB1.2, R17.2, R18.2, R19.2, R20.2, R21.1, R22.1, U3.4 (AVDD), U3.8 (AVDD), U3.11 (AVDD), U3.15 (AVDD), U3.17 (AVDD), U3.21 (AVDD)
/LiDAR Interface/EXRES1: R26.2, U3.10 (EXRES1)
/LiDAR Interface/LINKLED: J3.11 (LEDY_K), U3.25 (LINKLED)
/LiDAR Interface/MISO: ETH_MISO.1, U3.34 (MISO), U5.35 (PB14)
/LiDAR Interface/MOSI: ETH_MOSI.1, U3.35 (MOSI), U5.36 (PB15)
/LiDAR Interface/RCT: C21.1, J3.7 (RCT), R22.2
/LiDAR Interface/RXN: J3.6 (RD-), R19.1, U3.5 (RXN)
/LiDAR Interface/RXP: J3.3 (RD+), R20.1, U3.6 (RXP)
/LiDAR Interface/SCLK: ETH_SCLK.1, U3.33 (SCLK), U5.34 (PB13)
/LiDAR Interface/TCT: C20.1, J3.4 (TCT), R21.2
/LiDAR Interface/TOCAP: C25.1, U3.20 (TOCAP)
/LiDAR Interface/TXN: J3.2 (TD-), R17.1, U3.1 (TXN)
/LiDAR Interface/TXP: J3.1 (TD+), R18.1, U3.2 (TXP)
/LiDAR Interface/XI: C22.2, U3.30 (XI/CLKIN), Y1.3
/LiDAR Interface/XO: C23.2, U3.31 (XO), Y1.1
/LiDAR Interface/~INT: ETH_INT.1, U3.36 (~INT), U5.43 (PA10)
/LiDAR Interface/~RST: ETH_RST.1, U3.37 (~RST), U5.42 (PA9)
/LiDAR Interface/~SCS: ETH_SCS.1, U3.32 (~SCS), U5.33 (PB12)
/Microcontroller/BOOT0: BOOT.1, R31.1, U5.60 (BOOT0)
/Microcontroller/MCU_RST: C42.1, J5.1, MCU_RST.1, R33.2, R34.2, U5.7 (NRST)
/Microcontroller/OSC_IN: C39.2, U5.5 (PH0), Y3.3
/Microcontroller/OSC_OUT: C40.2, U5.6 (PH1), Y3.1
/Microcontroller/SWCLK: J5.3, U5.49 (PA14)
/Microcontroller/SWDIO: J5.2, U5.46 (PA13)
/Microcontroller/ULED: R32.1, U5.16 (PA2)
/Microcontroller/VREF+: R30.1, U5.13 (VREF+), VREF+.1
/Power Management/3.3VOUT: C12.1, C13.1, D3.1 (K), L2.2, R2.1, R14.1, R15.1, TP16.1
/Power Management/12VOUT: 12V#2.1, C8.1, C9.1, D6.1 (K), L1.2, R1.1, R11.1, R12.1
/Power Management/FB_3V3: FB_3V3.1, R14.2, R16.1, U2.4 (FB)
/Power Management/FB_12V: FB_12V.1, R11.2, R13.1, U1.4 (FB)
/Power Management/SW_3V3: C10.1, L2.1, SW_3V3.1, U2.2 (SW)
/Power Management/SW_12V: C6.1, L1.1, SW_12V.1, U1.2 (SW)
/Power Management/VIN: C7.1, C11.1, J2.1, U1.3 (VIN), U1.5 (EN), U2.3 (VIN), U2.5 (EN), VIN.1, VIN#2.1
CHASSIS_GND: C1.2, C2.2, J3.SH (SHIELD)
GND: C2.1, C3.2, C4.2, C5.2, C7.2, C8.2, C9.2, C11.2, C12.2, C13.2, C14.2, C15.1, C16.1, C17.2, C18.1, C19.1, C20.2, C21.2, C22.1, C23.1, C24.2, C25.2, C26.2, C27.1, C28.2, C29.1, C30.2, C31.1, C32.1, C33.1, C34.2, C35.1, C36.1, C37.1, C38.1, C39.1, C40.1, C41.2, C42.2, C43.1, D1.3 (A), D2.1 (K), D3.2 (A), D4.1 (K), D5.1 (K), D6.2 (A), J1.2, J2.2, J5.5, R13.2, R16.2, R26.1, R31.2, SW1.1, U1.1 (GND), U2.1 (GND), U3.3 (AGND), U3.9 (AGND), U3.14 (AGND), U3.16 (AGND), U3.19 (AGND), U3.29 (GND), U3.48 (AGND), U4.12 (WAKE), U4.13 (GND), U4.21 (GND), U5.12 (VSSA), U5.18 (VSS), U5.31 (VSS), U5.47 (VSS), U5.63 (VSS), Y1.2, Y1.4, Y2.2, Y2.4, Y3.2, Y3.4
unnamed: C1.1, R5.2, R6.2, R7.2, R8.2
unnamed: C5.1, R9.1, R10.1
unnamed: D2.2 (A), R12.2
unnamed: D4.2 (A), R15.2
unnamed: D5.2 (A), R32.2
unnamed: J3.14 (LEDG_A), R4.2
unnamed: J3.12 (LEDY_A), R3.2
unnamed: J3.5 (R1), R5.1
unnamed: J3.8 (R2), R6.1
unnamed: J3.10 (R3), R7.1
unnamed: J3.9 (R4), R8.1
unnamed: R34.1, SW1.2
unnamed: C6.2, U1.6 (CB)
unnamed: C10.2, U2.6 (CB)
unnamed: R25.2, U3.45 (PMODE0)
unnamed: R24.2, U3.44 (PMODE1)
unnamed: R23.2, U3.43 (PMODE2)
unnamed: R29.1, U5.1 (VBAT)
unnamed: C41.1, U5.30 (VCAP1)

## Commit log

2025-08-04 Initial commit
    Add KiCad project folder
    [LiDAR-CAN.kicad_pcb, LiDAR-CAN.kicad_sch]
2025-08-04 Add main schematic sheets
    [CAN-INTERFACE.kicad_sch, LIDAR-INTERFACE.kicad_sch, LiDAR-CAN.kicad_sch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]
2025-08-04 Add main components in schematic sheets
    [CAN-INTERFACE.kicad_sch, LIDAR-INTERFACE.kicad_sch, MCU.kicad_sch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]
2025-08-04 Add LiDAR Interface complete circuit
    [CAN-INTERFACE.kicad_sch, LIDAR-INTERFACE.kicad_sch, LiDAR-CAN.kicad_sch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]
2025-08-04 Add RJ45 connector circuit
    [LiDAR-CAN.kicad_sch]
2025-08-04 Add testpoints to LiDAR interface circuit
    [LIDAR-INTERFACE.kicad_sch]
2025-08-04 Add complete CAN Interface circuit
    [CAN-INTERFACE.kicad_sch, LIDAR-INTERFACE.kicad_sch]
2025-08-04 Add external connector circuit
    [CAN-INTERFACE.kicad_sch, LiDAR-CAN.kicad_sch]
2025-08-04 Complete 70% of schematic design
2025-08-05 Add complete MCU circuit
    [LiDAR-CAN.kicad_sch, MCU.kicad_sch]
2025-08-05 Add MCU connections in root sheet
    [LiDAR-CAN.kicad_sch, MCU.kicad_sch]
2025-08-05 Add power management circuit
    [CAN-INTERFACE.kicad_sch, LIDAR-INTERFACE.kicad_sch, MCU.kicad_sch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]
2025-08-05 Add power management connections in Root sheet
    [LiDAR-CAN.kicad_sch, MCU.kicad_sch, POWER-MANAGEMENT.kicad_sch]
2025-08-05 Feature schematic revision 1
    [CAN-INTERFACE.kicad_sch, LIDAR-INTERFACE.kicad_sch, LiDAR-CAN.kicad_sch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]
2025-08-05 Setup PCB stackup and routing
    [CAN-INTERFACE.kicad_sch, LiDAR-CAN.kicad_pcb]
2025-08-05 Start placement of components
    [CAN-INTERFACE.kicad_sch, LIDAR-INTERFACE.kicad_sch, LiDAR-CAN.kicad_pcb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]
2025-08-05 Add CAN and MCU placement
    [LIDAR-INTERFACE.kicad_sch, LiDAR-CAN.kicad_pcb, LiDAR-CAN.kicad_sch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]
2025-08-05 Update complete first placement
    [LIDAR-INTERFACE.kicad_sch, LiDAR-CAN.kicad_pcb, LiDAR-CAN.kicad_sch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]
2025-08-05 Add CAN interface routing
    [LiDAR-CAN.kicad_pcb]
2025-08-05 Add MCU routing
    [LiDAR-CAN.kicad_pcb]
2025-08-05 Add 3.3V regulator routing
    [LiDAR-CAN.kicad_pcb]
2025-08-05 Add 12V regulator routing
    [LiDAR-CAN.kicad_pcb]
2025-08-05 Add Ethernet interface routing
    [LIDAR-INTERFACE.kicad_sch, LiDAR-CAN.kicad_pcb]
2025-08-05 Add Ethernet connector routing
    [LiDAR-CAN.kicad_pcb]
2025-08-05 Add SPI buses routing
    [CAN-INTERFACE.kicad_sch, LiDAR-CAN.kicad_pcb]
2025-08-05 Complete routing and all nets
    [LiDAR-CAN.kicad_pcb]
2025-08-05 Add new silkscreen annotation
    [LiDAR-CAN.kicad_pcb]
2025-08-06 Complete silkscreen annotation
    [ECS-250-6-37B2-AGY-TR.stp, LiDAR-CAN.kicad_pcb, POWER-MANAGEMENT.kicad_sch]
2025-08-06 Feature schematic revision 2
    Main changes related to connection wires for easy layout and minor components adjustments from Rev 1
    [BOM-LiDAR-CAN.csv, CAN-INTERFACE.kicad_sch, LIDAR-INTERFACE.kicad_sch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]
2025-08-06 Feature layout revision 1
    [LiDAR-CAN.kicad_pcb]
2025-08-06 Release LiDAR-CAN Bridge Module v1.2.1
2025-08-06 Add REAME file
    [BOM-LiDAR-CAN.csv]
